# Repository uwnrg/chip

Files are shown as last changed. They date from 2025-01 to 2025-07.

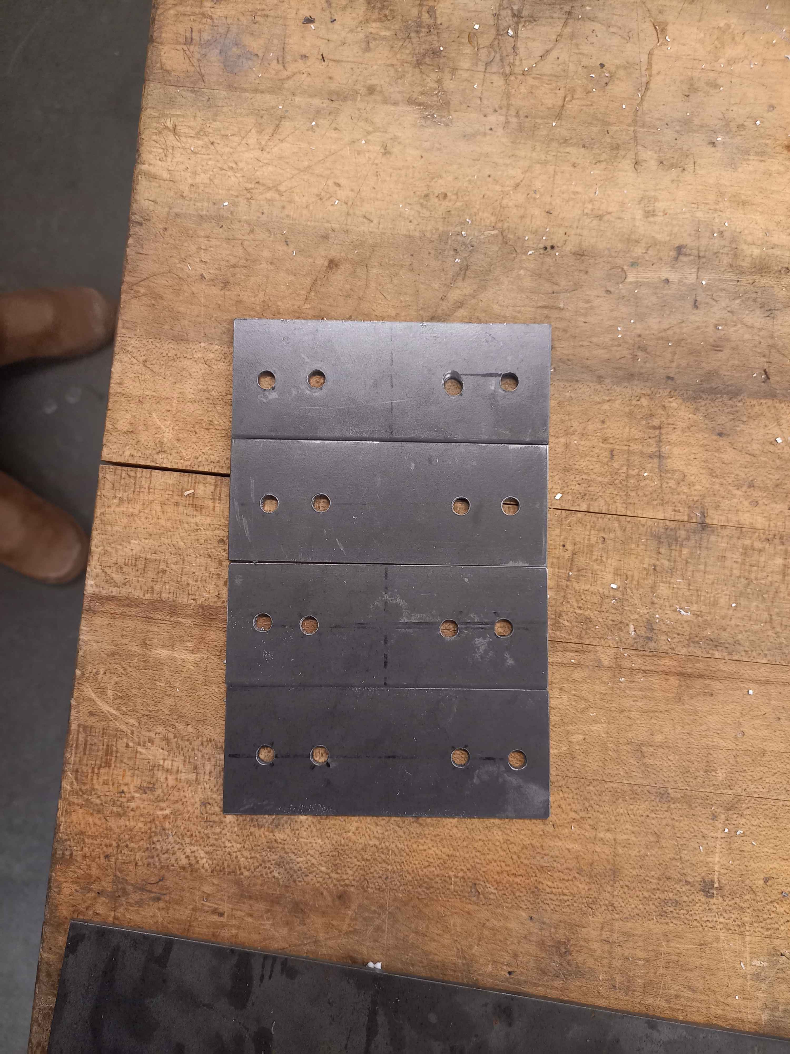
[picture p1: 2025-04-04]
mechanical/image/TuleenCuts.jpg

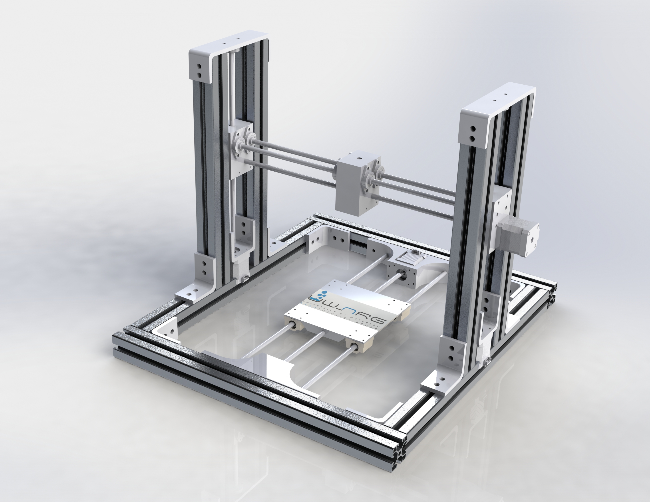
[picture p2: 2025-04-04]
mechanical/image/3DRender.JPG

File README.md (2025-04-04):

# C.H.I.P.

This is a repository for the Conductive Hydrodynamic Ink Printer (CHIP), our current fabrication robot. It is an additive manufacturing device that uses conductive, water-based nanoparticle inks to create circuits and sensors for a variety of applications. This robot allows us to explore applications in PCB fabrication, integrated devices, wearable sensors, and printed displays. Our aim with this platform is to broaden our robot development capabilities by adding a new fabrication technique to our team.

---

## Folder Structure

### 1. `controls`

**Purpose:**
The `controls` folder contains the code responsible for moving the robotic components in the device. This includes scripts and configurations that enable precise motion and control of the robotic elements.

**Contents:**

- Scripts for motor control and coordination.
- Configuration files for tuning robotic movement.
- Documentation related to control algorithms and parameters.

**Usage:**

1. Develop and test motion control algorithms in this folder.
2. Update configuration files to match the specific hardware setup.
3. Ensure proper documentation of control logic for maintainability.

### 2. `mechanical`

**Purpose:**
The `mechanical` folder contains all files and designs related to the mechanical aspects of the device. This includes the framing, fasteners, motor holders, threaded rod catchers, and other structural components.

**Contents:**

- `single_parts/`: Contains designs for individual components.
- `assemblies/`: Contains complete assemblies composed of multiple parts.
- CAD files, schematics, and design documentation.

**Usage:**

1. Store individual part designs in the `single_parts/` subfolder.
2. Save assembly designs in the `assemblies/` subfolder.
3. Update design documentation to reflect any changes to parts or assemblies.

### 3. `electronics`

**Purpose:**
The `electronics` folder is dedicated to the electronic components of the device. It includes diagrams, part lists, 3d models, and other resources needed for the electronic systems.

**Contents:**

- Circuit diagrams and schematics.
- Bill of materials (BOM) for electronic parts.
- Datasheets and reference materials for components.
- Documentation related to the electronic side of things

**Usage:**

1. Add circuit diagrams and schematics for the project.
2. Document electronic components in a structured BOM.
3. Store relevant datasheets and reference materials for easy access.
4. Any related documentation for this system's electronics

---

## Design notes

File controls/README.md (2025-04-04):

# C.H.I.P. Electronics

This is the controls side of the CHIP project. This includes the firmware as well as any interface software. The Marlin firmware can be found at https://github.com/MarlinFirmware/Marlin.

---

## Folder Structure

### 1. `marlin`

**Purpose:**
The `marlin` folder contains the configuration files for the open source marlin firmware.

**Contents:**

- Configuration files

**Usage:**

1. Modify the configuration files here, then pull Marlin firmware (2.1.1.3) and overwrite the default configurations with these files

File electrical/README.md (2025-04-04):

# C.H.I.P. Electronics

This is the electronics side of the CHIP project. This includes the circuit related components, such as pcb and cad designs. Firmware is found in the `controls` folder back in the main directory.

---

## Folder Structure

### 1. `cad_design`

**Purpose:**
The `cad_design` folder contains CAD files related to the circuity. This mainly includes housing for these circuits.

**Contents:**

- Solidwork files for PSU
- PCB box files

**Usage:**

1. Any CAD files should be placed here
2. 3D printing files, like GCODE can also go here

### 2. `documentation`

**Purpose:**
The `documentation` folder contains documentation on the entire design process for the electronic side of things.

**Contents:**

- Documentation on processes
- Images of said processes

**Usage:**

1. Store important information on the workings of the fabrication process
2. Any information on recreating the project

### 3. `schematic`

**Purpose:**
The `schematic` folder is dedicated to the electronic schematics for PCB design.

**Contents:**

- Circuit diagrams and schematics.
- Datasheets and reference materials for components.

**Usage:**

1. Add circuit diagrams and schematics for the project.
2. Store relevant datasheets and reference materials for easy access.

---

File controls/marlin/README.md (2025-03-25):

# What is Marlin
Marlin is a self-containing application that lives directly on the motherboard that controls the real-time movement of the machine.

# How to download & configure Marlin
As of March 2, 2025, we are using Marlin 2.1.1.3, available here: https://github.com/MarlinFirmware/Marlin/releases/tag/2.1.1.3.
1. Download & unzip the downloaded Marlin zipped folder.
2. Replace the downloaded configuration.h and configuration_adv.h files with the ones found in uwnrg/chip/controls/marlin.
3. Using VS Code with the PlatformIO extesion downloaded, ensure that your project folder is your Marlin folder, locate a checkmark icon in the bottom left to compile your code.
4. (For 8-bit boards) Once compiled, still in VS Code, enter the platformio.ini file, locate the build enviornment declaration statement (something like [env:name]), and specify a upload speed and port. Click the arrow icon in the bottom left blue ribbon. This whole step is easier done on the Arduino IDE.
5. (For 32-bit) After compilation, find the firmware.bin file in the Marlin folder in the .pio/build name folder. Put this file on an SD and load it into the printer.
   
**Important:** Once the files are complied, all commented lines are deleted, so it is important to compile only once the configuration files include all data. Our plan is to finish the config. files and compile it once, and redistribute it as one file to eliminate the need to repeat the steps above everytime.

# Important information about the Marlin configuration files
The configuration files are incomplete as of March 2, 2025 due to some unknown parameters as of now. Below are the defined parameters in the config files, as well as the parameters that still need to be defined. The configuration_adv.h file has not been modified from the Marlin source code.

## Configuration.h Parameters
| Parameter | Value |
|--- | ---|
|MOTHERBOARD|BOARD_RAMPS_14_EFB|
|SERIAL_PORT|-1 _(USB emulated serial port)_|
|BAUDRATE|250000 _(Default, lower it if line number and checksum errors appear, 115200)_|
|E0|A4988|
|X|A4988|
|Y|A4988|
|Z|A4988|
|EXTRUDERS|1|
|DEFAULT_NOMINAL_FILAMENT_DIA|1.75 _(Default, needs to be revised later)_|
|TEMP_SENSOR_0 & 1 & 2|1 _(on)_|
|X-Min/Max & Y-Min/Max & Z-Min/Max|Configured|
|LCD Controller|REPRAP_DISCOUNT_FULL_GRAPHIC_SMART_CONTROLLER _(unsure)_|
|SDSUPPORT|Enabled _(unsure)_|
|TEMP_STAT_LEDS| Enabled _(unsure as of now if our leds will be used for temp)_|
|**Servo Probes**|Probes have not been enabled, need to figure it out|
|**X&Y Bed Size**|Not Set|
|**Ink Preheat Settings**|Not Set|
|**Temp Sensor Locations**|Not Set|

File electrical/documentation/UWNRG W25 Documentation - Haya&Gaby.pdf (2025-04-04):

# End of term documentation

Haya Dakhil & Gaby (most tasks were done together)

### U-bracket Mount Machining

Done by: Haya, Gaby with the help of Joshua
- Drilled holes in the U-bracket
- As of right now, we are working on the work order to be completed so the brackets can be bent
Attachments:
- ZStepperHolderDrawing.jpg - Preliminary 2D sketch in SOLIDWORKS, uploaded as JPG
- ZStepperHolderPart.png - Snapshot of machined part
Tools used: SOLIDWORKS, UW E5 Machine shop

### Dimensioning of PSU, Circuit board, Screen

Done by: Haya
- Measured dimensions of the PSU including hole placements, the screen, and the control board.
- These measurements were used for CAD and assembly planning.
- Measured in inches
Attachments:
- | Dimensions.pdf | - measurements and its diagrams

### CAD Design and Printing - PSU Box

Done by: Haya
- Designed the PSU enclosure, which includes two parts:
- Base, with a wire slot
- A slide-in lid
During testing, I had to file down the top part of the base slightly for the PSU to fit through Attachments:
- PSU_LID.SLDPRT
- PSU_BODY.SLDPRT
- PSUCasePhoto.png
Tools: SOLIDWORKS, 3D printer from RPC

### Preliminary Sketch - Fluid Deposition Mechanism

Done by: Haya and Gaby
- Created a mechanism for fluid deposition for the screen-printing process.
- The design was based on constraints to use a syringe and stepper motor
- Components can be CADded, but need to be screwed together
- Next steps: Create a schematic drawing and CAD parts surrounding the dimensions of our syringe and stepper motor

Attachments:
- FluidIntegration.png file explaining the concept, and its components needed
- https://www.youtube.com/watch?v=Ya2Ck09Q0-Q&start=1 Link showcasing process

### PCB assembly and wiring

Done by: Haya and Gaby
- Most of the PCB work was done by Andrew, but we finalized it by doing its final connections of male and female connector wires.
- We followed the documentation in a link I’ll provide.
- An issue came up where the Z-axis connection didn't fit, so Andrew soldered the wires directly.
Attachments:
- PCBAssembly.png Snapshot showing the assembly
- https://osoyoo.com/2016/07/03/reprap-3d-printer-circuit-connection-graph/ Our guide

### Electrical components - PSU/Components assembly

Done by: Haya, Gaby, Ahyan. Dany
- Helped attach electrical components to the PSU and tested wire connections.
- We submitted a photo of this, though note: the wires have been continuously connected and disconnected due to ongoing testing
Attachments:
- ComponentsAssembly.png

### Education Liaison

Done by: Haya
- Acted as the Education Liaison for the team. My role was to support the Education sub-team by helping them understand the technical aspects of the project.
- I connected with them to clarify details about the mechanical and electrical subsystems and answered any questions they had so they could complete their documentation accurately.
- We only had time to mainly discuss the chemical side of the curriculum

### Software/Tools Used

- SolidWorks 2023 / 2024
- PDF editor: done on Goodnotes
- Machining: UW E5 Machine shop
- Soldering & electrical work done using standard lab equipment

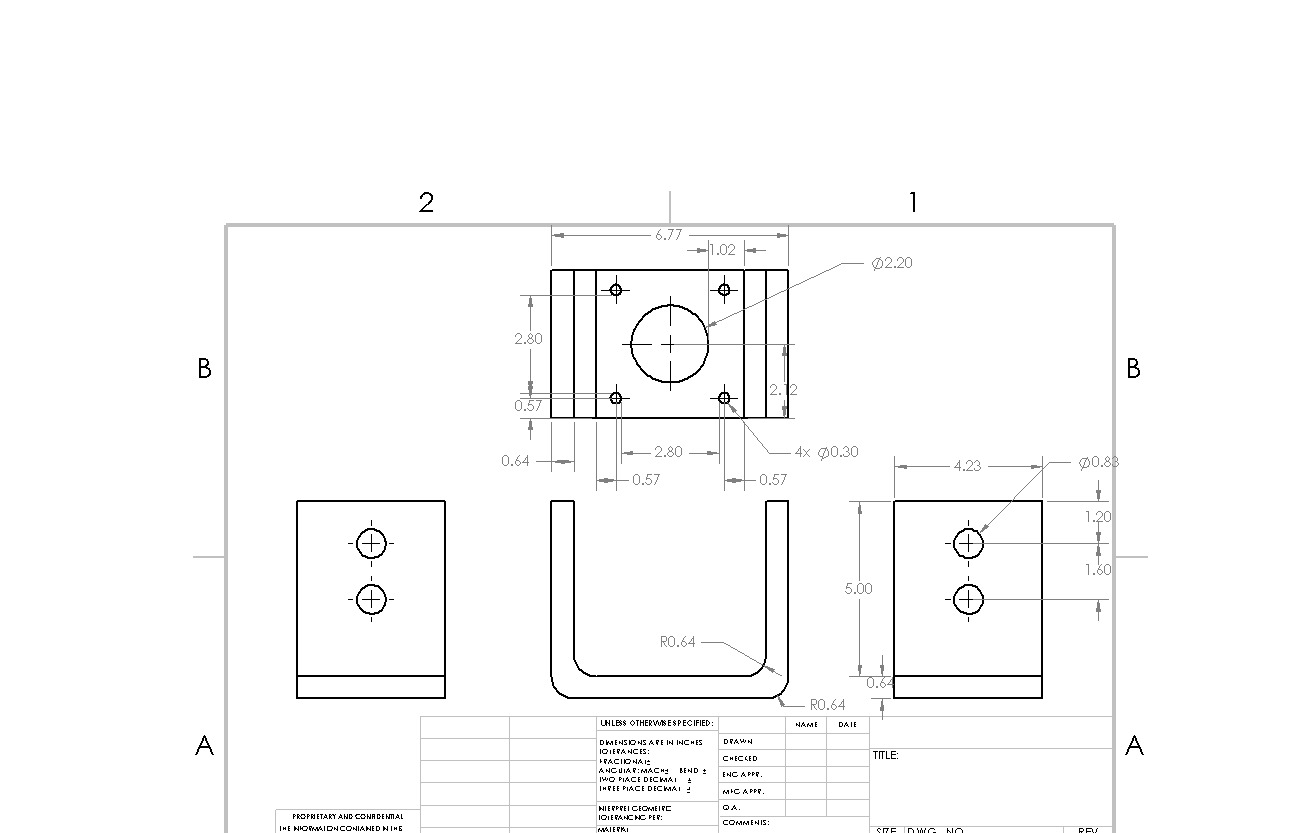
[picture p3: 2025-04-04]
mechanical/image/ZStepperHolderDrawing.JPG

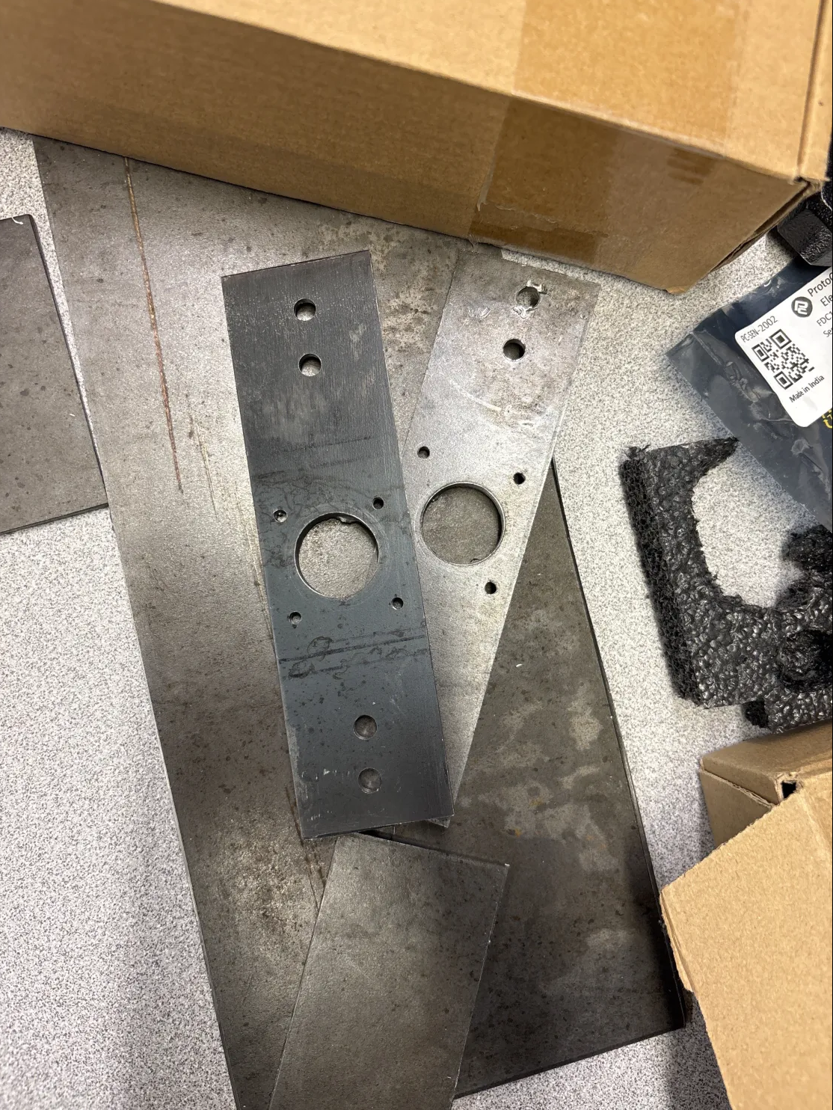
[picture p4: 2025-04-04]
mechanical/image/ZStepperHolderPart.png

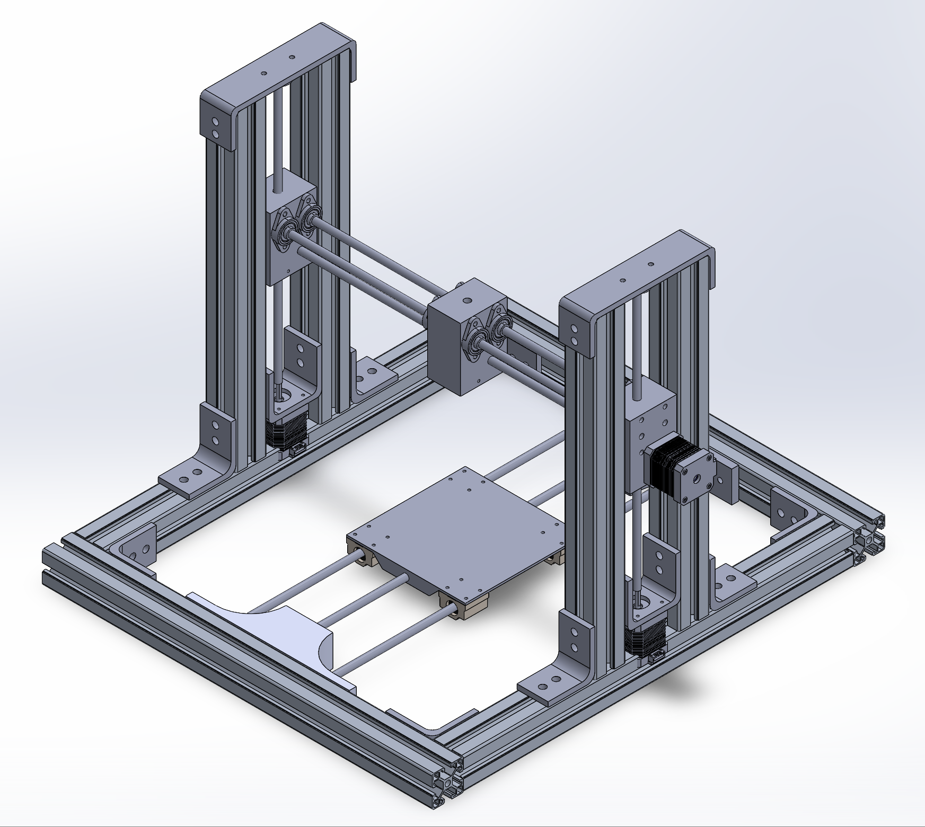
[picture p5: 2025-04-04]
mechanical/image/3DModel.png

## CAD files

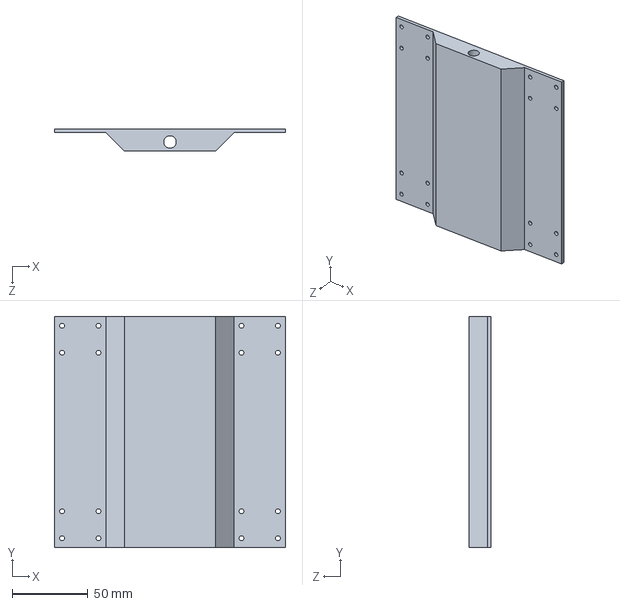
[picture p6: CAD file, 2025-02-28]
mechanical/part/X-axis baseplate.SLDPRT
152.4 x 152.4 x 14.8 mm

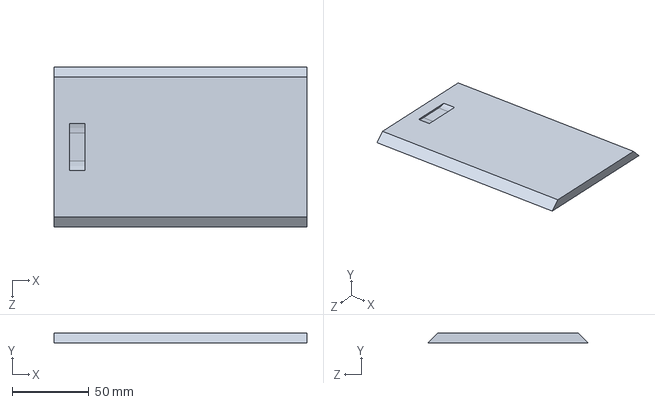
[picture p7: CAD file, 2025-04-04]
electrical/cad_design/PSU_LID.SLDPRT
165.1 x 6.68 x 104.6 mm

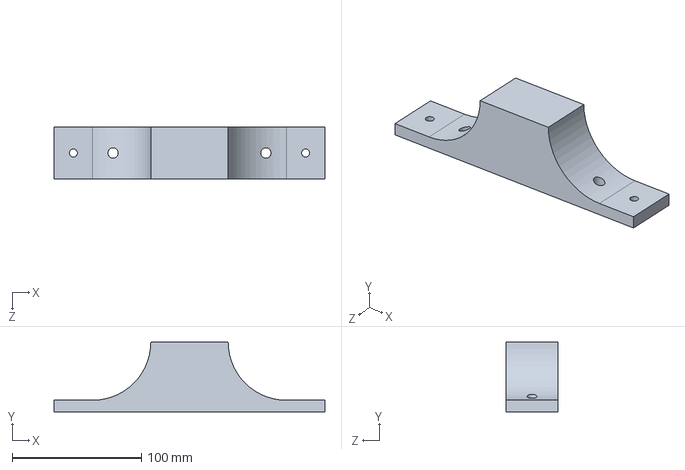
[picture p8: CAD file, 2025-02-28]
mechanical/part/Motor_Holder Updated.SLDPRT
210.0 x 54.0 x 40.0 mm

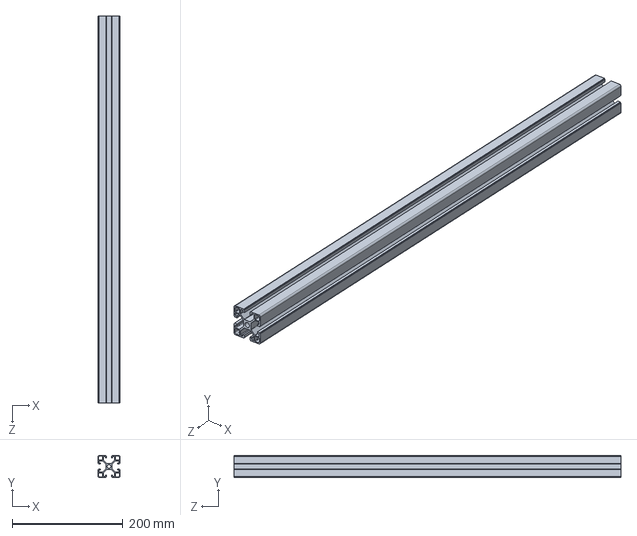
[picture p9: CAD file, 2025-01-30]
mechanical/part/AlShort.SLDPRT
40.0 x 40.0 x 700.0 mm

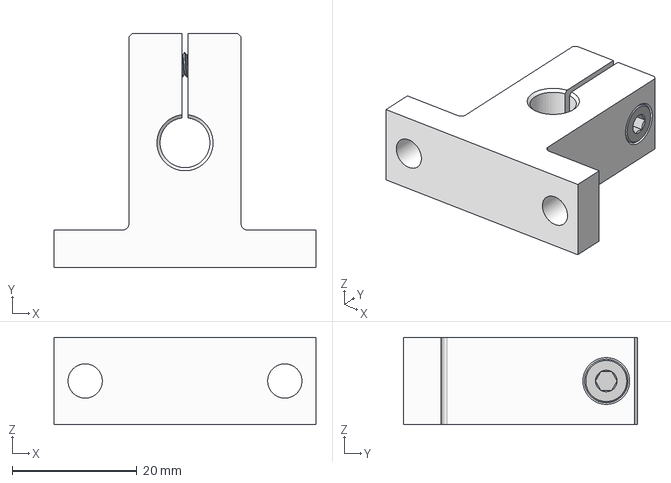
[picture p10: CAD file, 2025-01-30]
mechanical/part/SK8 Linear Shaft Support, 8mm v4.step
42.0 x 37.5 x 14.0 mm

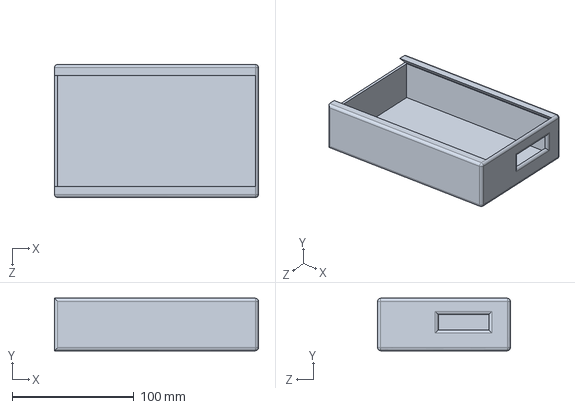
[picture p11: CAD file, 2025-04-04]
electrical/cad_design/PSU_BODY.SLDPRT
167.6 x 43.2 x 109.2 mm

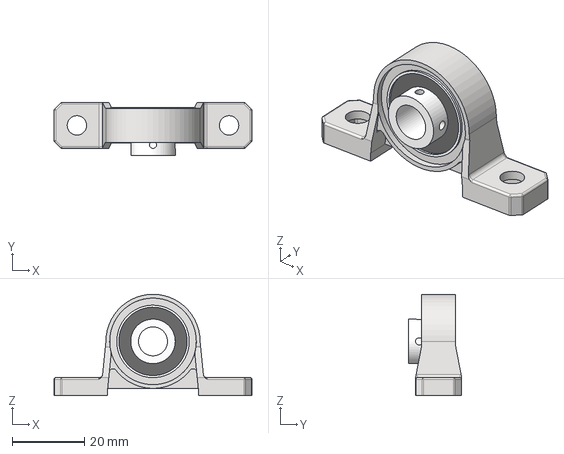
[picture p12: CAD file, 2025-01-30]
mechanical/part/Bearing_Mount_8mm.stp
54.6 x 14.8 x 28.0 mm

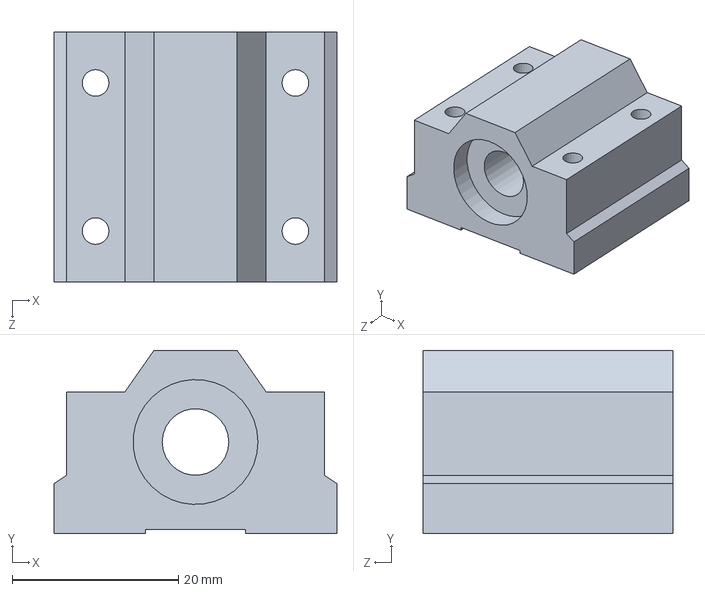
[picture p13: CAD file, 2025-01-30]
mechanical/part/LinearRodGuide.SLDPRT
34.0 x 22.0 x 30.0 mm

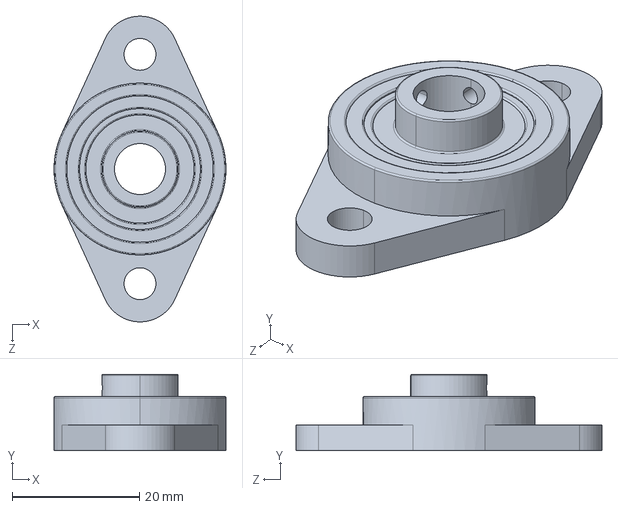
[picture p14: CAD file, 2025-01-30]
mechanical/part/KFL08.STEP
27.0 x 12.0 x 48.0 mm

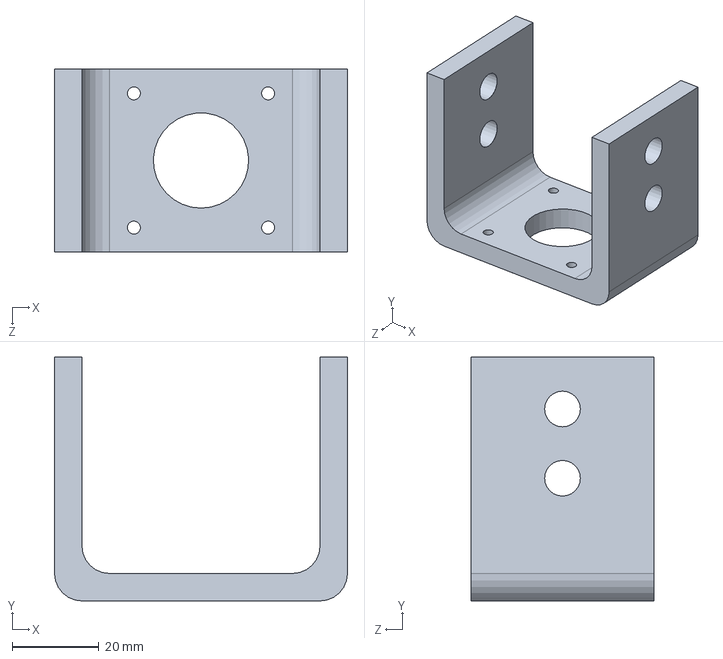
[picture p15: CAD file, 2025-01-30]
mechanical/part/ZStepperHolder.SLDPRT
67.7 x 56.3 x 42.3 mm

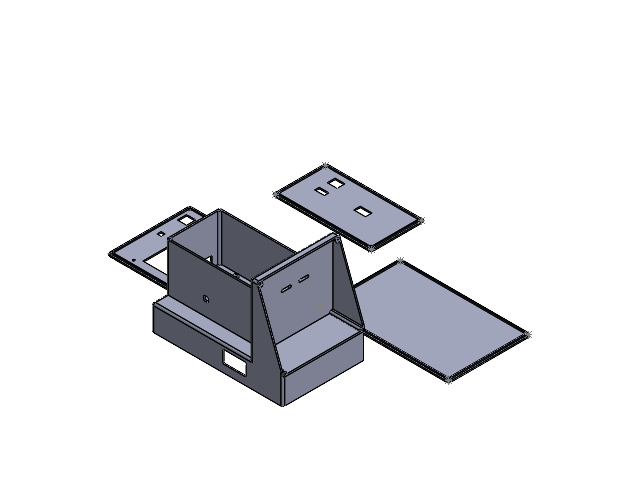
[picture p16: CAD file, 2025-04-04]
electrical/cad_design/Assembly PCB Box.SLDASM
pcb box lid
power supply lid
screen lid
pcb box main

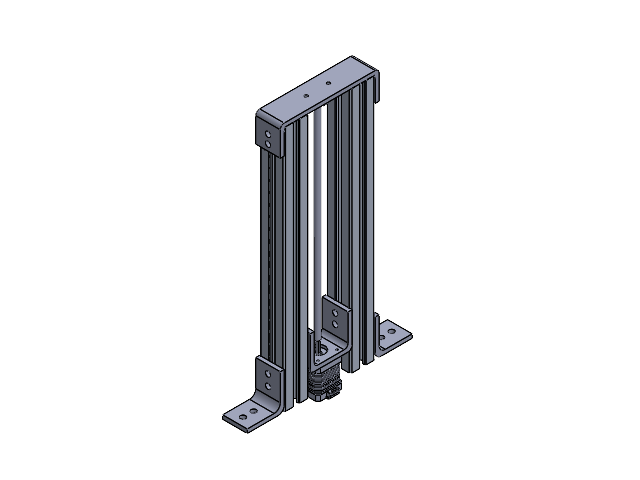
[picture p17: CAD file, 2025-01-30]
mechanical/assembly/Z_axis.SLDASM
AlShort x 2
LBracket x 2
ZStepperHolder
ZTopBracket
Stepper
KFL08
LinearRod

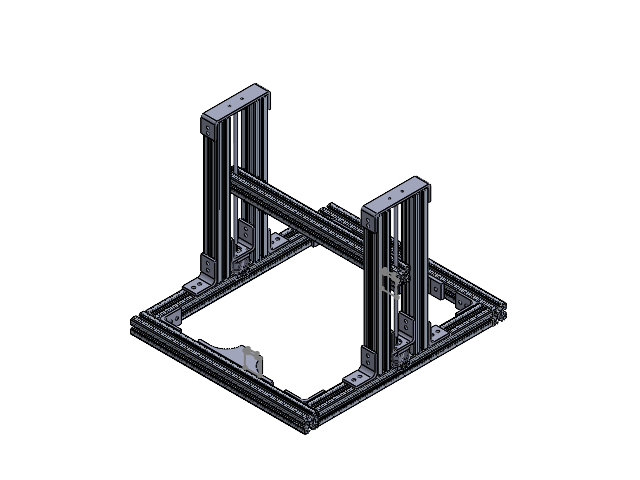
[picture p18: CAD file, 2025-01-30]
mechanical/assembly/PrinterAssem.SLDASM
AlExtrusion x 5
LBracket x 8
AlShort x 4
ZStepperHolder x 2
ZTopBracket x 2
Stepper x 2
KFL08 x 2
LinearRod x 2
Motor_Holder x 2

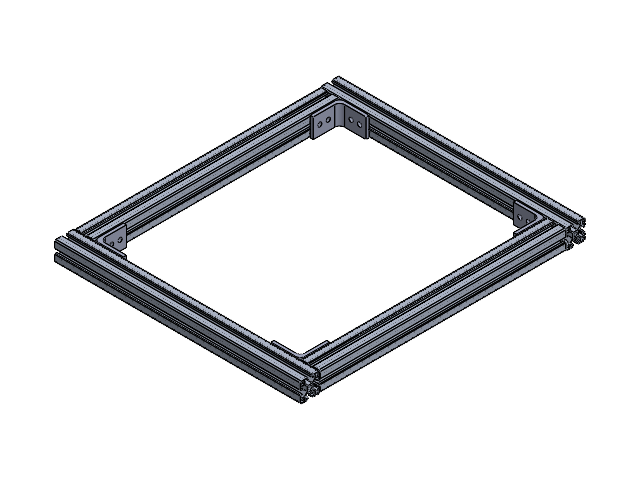
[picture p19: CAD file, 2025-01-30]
mechanical/part/Base_frame.SLDASM
AlExtrusion x 4
LBracket x 4

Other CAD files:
electrical/cad_design/pcb box main.gcode.3mf
electrical/cad_design/Lids.gcode.3mf
mechanical/part/AlExtrusion.SLDPRT
mechanical/part/Motor_Holder.SLDPRT
mechanical/part/KFL08.SLDPRT
mechanical/part/LBracket.SLDPRT
mechanical/part/LinearRod.SLDPRT
mechanical/part/ThreadedRodNut.step
mechanical/part/ZTopBracket.SLDPRT

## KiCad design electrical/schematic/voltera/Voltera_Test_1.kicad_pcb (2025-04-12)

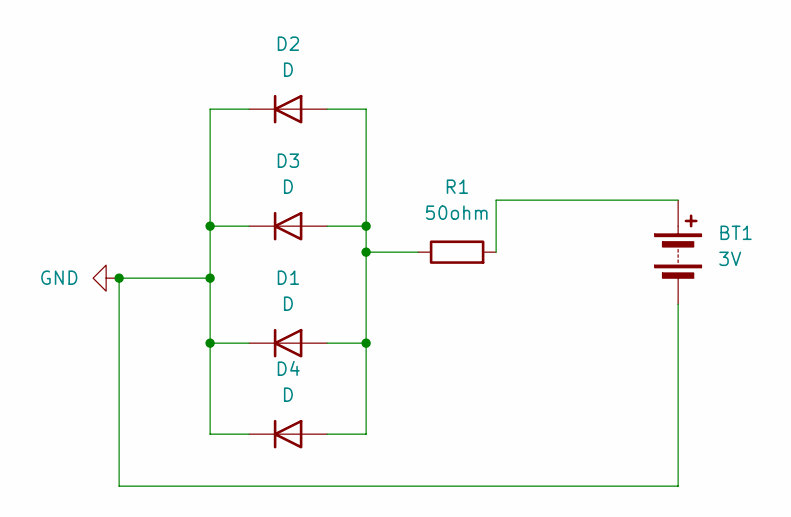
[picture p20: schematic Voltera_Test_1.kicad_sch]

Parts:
BT1: 3V; PinHeader_1x02_P1.00mm_Vertical
D1, D2: D; D_0402_1005Metric
D3, D4: D; D_DO-15_P3.81mm_Vertical_KathodeUp
R1: 50ohm; R_Axial_DIN0204_L3.6mm_D1.6mm_P5.08mm_Horizontal

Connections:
GND: BT1.2 (-), D1.1 (K), D2.1 (K), D3.1 (K), D4.1 (K)
unnamed: BT1.1 (+), R1.2
unnamed: D1.2 (A), D2.2 (A), D3.2 (A), D4.2 (A), R1.1

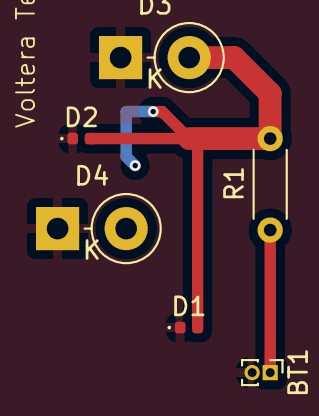
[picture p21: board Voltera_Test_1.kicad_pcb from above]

Board: 2 copper layers, 6 parts (0 on the bottom side), 3 nets.

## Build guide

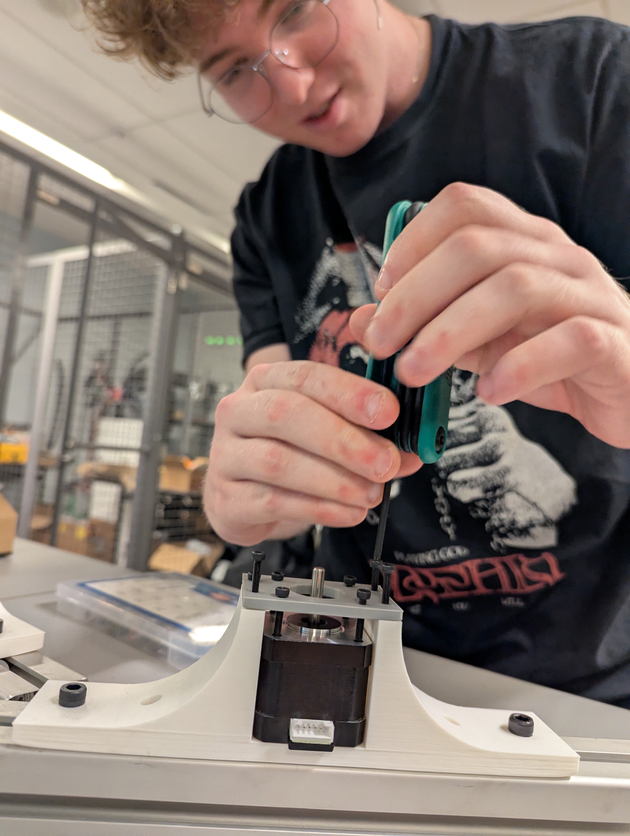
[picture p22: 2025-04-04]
mechanical/image/MotorAssembly.jpg

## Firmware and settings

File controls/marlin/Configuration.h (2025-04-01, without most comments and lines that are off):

#pragma once
#define CONFIGURATION_H_VERSION 02010100
#define STRING_CONFIG_H_AUTHOR "Katerina Bogdanovich" // Who made the changes.
#define SHOW_BOOTSCREEN
  #define MOTHERBOARD BOARD_RAMPS_14_EFB
#define SERIAL_PORT 0
#define BAUDRATE 250000
#define CUSTOM_MACHINE_NAME "C.H.I.P."
#define X_DRIVER_TYPE  A4988
#define Y_DRIVER_TYPE  A4988
#define Z_DRIVER_TYPE  A4988
#define E0_DRIVER_TYPE A4988
#define EXTRUDERS 1
#define DEFAULT_NOMINAL_FILAMENT_DIA 1.75
#define TEMP_SENSOR_0 1
#define TEMP_SENSOR_1 1
#define TEMP_SENSOR_2 1
#define TEMP_SENSOR_3 0
#define TEMP_SENSOR_4 0
#define TEMP_SENSOR_5 0
#define TEMP_SENSOR_6 0
#define TEMP_SENSOR_7 0
#define TEMP_SENSOR_BED 0
#define TEMP_SENSOR_PROBE 0
#define TEMP_SENSOR_CHAMBER 0
#define TEMP_SENSOR_COOLER 0
#define TEMP_SENSOR_BOARD 0
#define TEMP_SENSOR_REDUNDANT 0
#define DUMMY_THERMISTOR_998_VALUE  25
#define DUMMY_THERMISTOR_999_VALUE 100
#if TEMP_SENSOR_IS_MAX_TC(0)
  #define MAX31865_SENSOR_OHMS_0      100 // (Ω) Typically 100 or 1000 (PT100 or PT1000)
  #define MAX31865_CALIBRATION_OHMS_0 430 // (Ω) Typically 430 for Adafruit PT100; 4300 for Adafruit PT1000
#endif
#if TEMP_SENSOR_IS_MAX_TC(1)
  #define MAX31865_SENSOR_OHMS_1      100
  #define MAX31865_CALIBRATION_OHMS_1 430
#endif
#if HAS_E_TEMP_SENSOR
  #define TEMP_RESIDENCY_TIME         10  // (seconds) Time to wait for hotend to "settle" in M109
  #define TEMP_WINDOW                  1  // (°C) Temperature proximity for the "temperature reached" timer
  #define TEMP_HYSTERESIS              3  // (°C) Temperature proximity considered "close enough" to the target
#endif
#if TEMP_SENSOR_BED
  #define TEMP_BED_RESIDENCY_TIME     10  // (seconds) Time to wait for bed to "settle" in M190
  #define TEMP_BED_WINDOW              1  // (°C) Temperature proximity for the "temperature reached" timer
  #define TEMP_BED_HYSTERESIS          3  // (°C) Temperature proximity considered "close enough" to the target
#endif
#if TEMP_SENSOR_CHAMBER
  #define TEMP_CHAMBER_RESIDENCY_TIME 10  // (seconds) Time to wait for chamber to "settle" in M191
  #define TEMP_CHAMBER_WINDOW          1  // (°C) Temperature proximity for the "temperature reached" timer
  #define TEMP_CHAMBER_HYSTERESIS      3  // (°C) Temperature proximity considered "close enough" to the target
#endif
#if TEMP_SENSOR_REDUNDANT
  #define TEMP_SENSOR_REDUNDANT_SOURCE    E1  // The sensor that will provide the redundant reading.
  #define TEMP_SENSOR_REDUNDANT_TARGET    E0  // The sensor that we are providing a redundant reading for.
  #define TEMP_SENSOR_REDUNDANT_MAX_DIFF  10  // (°C) Temperature difference that will trigger a print abort.
#endif
#define HEATER_0_MINTEMP   5
#define HEATER_1_MINTEMP   5
#define HEATER_2_MINTEMP   5
#define HEATER_3_MINTEMP   5
#define HEATER_4_MINTEMP   5
#define HEATER_5_MINTEMP   5
#define HEATER_6_MINTEMP   5
#define HEATER_7_MINTEMP   5
#define BED_MINTEMP        5
#define CHAMBER_MINTEMP    5
#define HEATER_0_MAXTEMP 275
#define HEATER_1_MAXTEMP 275
#define HEATER_2_MAXTEMP 275
#define HEATER_3_MAXTEMP 275
#define HEATER_4_MAXTEMP 275
#define HEATER_5_MAXTEMP 275
#define HEATER_6_MAXTEMP 275
#define HEATER_7_MAXTEMP 275
#define BED_MAXTEMP      150
#define CHAMBER_MAXTEMP  60
#define HOTEND_OVERSHOOT 15   // (°C) Forbid temperatures over MAXTEMP - OVERSHOOT
#define BED_OVERSHOOT    10   // (°C) Forbid temperatures over MAXTEMP - OVERSHOOT
#define COOLER_OVERSHOOT  2   // (°C) Forbid temperatures closer than OVERSHOOT
#define PIDTEMP          // See the PID Tuning Guide at https://reprap.org/wiki/PID_Tuning
#define BANG_MAX 255     // Limits current to nozzle while in bang-bang mode; 255=full current
#define PID_MAX BANG_MAX // Limits current to nozzle while PID is active (see PID_FUNCTIONAL_RANGE below); 255=full current
#define PID_K1 0.95      // Smoothing factor within any PID loop
    #define DEFAULT_Kp  22.20
    #define DEFAULT_Ki   1.08
    #define DEFAULT_Kd 114.00
#define MAX_BED_POWER 255 // limits duty cycle to bed; 255=full current
#define MAX_CHAMBER_POWER 255 // limits duty cycle to chamber heater; 255=full current
  #define PID_FUNCTIONAL_RANGE 10 // If the temperature difference between the target temperature and the actual temperature
#define PREVENT_COLD_EXTRUSION
#define EXTRUDE_MINTEMP 170
#define PREVENT_LENGTHY_EXTRUDE
#define EXTRUDE_MAXLENGTH 200
#define THERMAL_PROTECTION_HOTENDS // Enable thermal protection for all extruders
#define THERMAL_PROTECTION_BED     // Enable thermal protection for the heated bed
#define THERMAL_PROTECTION_CHAMBER // Enable thermal protection for the heated chamber
#define THERMAL_PROTECTION_COOLER  // Enable thermal protection for the laser cooling
#define USE_XMIN_PLUG
#define USE_YMIN_PLUG
#define USE_ZMIN_PLUG
#define USE_XMAX_PLUG
#define USE_YMAX_PLUG
#define USE_ZMAX_PLUG
#define ENDSTOPPULLUPS
#define X_MIN_ENDSTOP_INVERTING false // Set to true to invert the logic of the endstop.
#define Y_MIN_ENDSTOP_INVERTING false // Set to true to invert the logic of the endstop.
#define Z_MIN_ENDSTOP_INVERTING false // Set to true to invert the logic of the endstop.
#define I_MIN_ENDSTOP_INVERTING false // Set to true to invert the logic of the endstop.
#define J_MIN_ENDSTOP_INVERTING false // Set to true to invert the logic of the endstop.
#define K_MIN_ENDSTOP_INVERTING false // Set to true to invert the logic of the endstop.
#define U_MIN_ENDSTOP_INVERTING false // Set to true to invert the logic of the endstop.
#define V_MIN_ENDSTOP_INVERTING false // Set to true to invert the logic of the endstop.
#define W_MIN_ENDSTOP_INVERTING false // Set to true to invert the logic of the endstop.
#define X_MAX_ENDSTOP_INVERTING false // Set to true to invert the logic of the endstop.
#define Y_MAX_ENDSTOP_INVERTING false // Set to true to invert the logic of the endstop.
#define Z_MAX_ENDSTOP_INVERTING false // Set to true to invert the logic of the endstop.
#define I_MAX_ENDSTOP_INVERTING false // Set to true to invert the logic of the endstop.
#define J_MAX_ENDSTOP_INVERTING false // Set to true to invert the logic of the endstop.
#define K_MAX_ENDSTOP_INVERTING false // Set to true to invert the logic of the endstop.
#define U_MAX_ENDSTOP_INVERTING false // Set to true to invert the logic of the endstop.
#define V_MAX_ENDSTOP_INVERTING false // Set to true to invert the logic of the endstop.
#define W_MAX_ENDSTOP_INVERTING false // Set to true to invert the logic of the endstop.
#define Z_MIN_PROBE_ENDSTOP_INVERTING false // Set to true to invert the logic of the probe.
#define DEFAULT_AXIS_STEPS_PER_UNIT   { 80, 80, 400, 500 }
#define DEFAULT_MAX_FEEDRATE          { 300, 300, 5, 25 }
#define DEFAULT_MAX_ACCELERATION      { 3000, 3000, 100, 10000 }
#define DEFAULT_ACCELERATION          3000    // X, Y, Z and E acceleration for printing moves
#define DEFAULT_RETRACT_ACCELERATION  3000    // E acceleration for retracts
#define DEFAULT_TRAVEL_ACCELERATION   3000    // X, Y, Z acceleration for travel (non printing) moves
#define DEFAULT_EJERK    5.0  // May be used by Linear Advance
  #define JUNCTION_DEVIATION_MM 0.013 // (mm) Distance from real junction edge
  #define JD_HANDLE_SMALL_SEGMENTS    // Use curvature estimation instead of just the junction angle
#define Z_MIN_PROBE_USES_Z_MIN_ENDSTOP_PIN
#define NOZZLE_TO_PROBE_OFFSET { 10, 10, 0 }
#define PROBING_MARGIN 10
#define XY_PROBE_FEEDRATE (133*60)
#define Z_PROBE_FEEDRATE_FAST (4*60)
#define Z_PROBE_FEEDRATE_SLOW (Z_PROBE_FEEDRATE_FAST / 2)
#define Z_CLEARANCE_DEPLOY_PROBE   10 // Z Clearance for Deploy/Stow
#define Z_CLEARANCE_BETWEEN_PROBES  5 // Z Clearance between probe points
#define Z_CLEARANCE_MULTI_PROBE     5 // Z Clearance between multiple probes
#define Z_PROBE_LOW_POINT          -2 // Farthest distance below the trigger-point to go before stopping
#define Z_PROBE_OFFSET_RANGE_MIN -20
#define Z_PROBE_OFFSET_RANGE_MAX 20
#define X_ENABLE_ON 0
#define Y_ENABLE_ON 0
#define Z_ENABLE_ON 0
#define E_ENABLE_ON 0 // For all extruders
#define DISABLE_X false
#define DISABLE_Y false
#define DISABLE_Z false
#define DISABLE_E false             // Disable the extruder when not stepping
#define DISABLE_INACTIVE_EXTRUDER   // Keep only the active extruder enabled
#define INVERT_X_DIR false
#define INVERT_Y_DIR true
#define INVERT_Z_DIR false
#define INVERT_E0_DIR false
#define INVERT_E1_DIR false
#define INVERT_E2_DIR false
#define INVERT_E3_DIR false
#define INVERT_E4_DIR false
#define INVERT_E5_DIR false
#define INVERT_E6_DIR false
#define INVERT_E7_DIR false
#define X_HOME_DIR -1
#define Y_HOME_DIR -1
#define Z_HOME_DIR -1
#define X_BED_SIZE 200
#define Y_BED_SIZE 200
#define X_MIN_POS 0
#define Y_MIN_POS 0
#define Z_MIN_POS 0
#define X_MAX_POS X_BED_SIZE
#define Y_MAX_POS Y_BED_SIZE
#define Z_MAX_POS 200
#define MIN_SOFTWARE_ENDSTOPS
  #define MIN_SOFTWARE_ENDSTOP_X
  #define MIN_SOFTWARE_ENDSTOP_Y
  #define MIN_SOFTWARE_ENDSTOP_Z
  #define MIN_SOFTWARE_ENDSTOP_I
  #define MIN_SOFTWARE_ENDSTOP_J
  #define MIN_SOFTWARE_ENDSTOP_K
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

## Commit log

2025-01-30 initialize mechanical directory
    [AlExtrusion.SLDPRT, AlShort.SLDPRT, Base_frame.SLDASM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]
2025-02-17 Add files via upload
    Electrical Schematic for CHIP based on RAMPS 4.1
2025-02-20 extract schematic files
    [CHIP_schematic.kicad_pcb, CHIP_schematic.kicad_sch]
2025-02-28 Add files via upload
    Updated motor holder to have right hole sizes for linear rods. Adjusted distance between linear rods to match x-axis baseplate rod guides and threaded rod catcher
    [Motor_Holder Updated.SLDPRT, X-axis baseplate.SLDPRT]
2025-03-02 Create the marlin folder
2025-03-02 Delete controls/marlin
    Wasn't a folder so had to delete
2025-03-02 Create README.md for Marlin
    Ok now it is a folder 👍
2025-03-02 Revert "Create README.md for Marlin"
2025-03-02 Uploading marlin config files
    [Configuration.h, Configuration_adv.h]
2025-03-25 Create PCB Box
2025-04-01 Update Configuration.h
    modified to fix compilation errors
    [Configuration.h]
2025-04-04 re-organize repo; add haya/gaby stuff
    [Assembly PCB Box.SLDASM, CHIP_schematic.kicad_pcb, CHIP_schematic.kicad_sch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]
2025-04-12 adding Dany's stuff
    [Voltera_Test_1.kicad_pcb, Voltera_Test_1.kicad_sch]
2025-07-18 Add files via upload
    simple traces to test x and y motors
    [Gcode simple test.kicad_pcb]

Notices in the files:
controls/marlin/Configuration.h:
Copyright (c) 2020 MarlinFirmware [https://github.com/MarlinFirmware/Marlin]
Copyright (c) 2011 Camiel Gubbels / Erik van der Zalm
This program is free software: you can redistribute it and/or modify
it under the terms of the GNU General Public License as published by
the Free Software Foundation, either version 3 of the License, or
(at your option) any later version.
